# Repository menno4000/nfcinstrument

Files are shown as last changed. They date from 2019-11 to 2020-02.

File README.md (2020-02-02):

# Near Field Groovinator

Fast and easy groove creation

## Arduino racket
We are using an Arduino NANO with the bluetooth HC05 and an NFC Shield as a racket. 
The racket can read notes from RFID chips and send them via bluetooth to the Raspberry Pi. 

You also have two buttons to switch between thh current channel which represents a tone layer (eg. Kick, Snare, HiHat).

## Raspberry Pi 3 - Sequencer, Bluetooth receiver & Displayer
The Raspberry Pi receives signals from the Arduino and starts a Sequencer. 
It will add notes to different channels and start playing them sequentially.

With some hardware knobs and buttons you can control the sequencer and record your notes.

### Displayer
For visual support we will use an already existing LED matrix (16 x MAX7219). 
It will show the programmed sequence and give additional information.

### Hardware-Setup

General Overview of Pins on the Raspberry Pi 3:

Pin Layout


For buttons and the rotary encoder use this table to connect:

| Rotary Encoder | Pins | GPIO |
|---|---|---|
| beat_changer | 11, 13, 15 | 17, 27, 22 |
| bpm_changer | 12, 16, 18 | 18, 23, 24 |
| volume_changer | 29, 31, 32 | 5, 6, 13 |
| Buttons | | |
| play_button | 36 | 16 |
| reset_button | 38 | 20 |
| metro_button | 40 | 21 |
| record_button  | 26 |  7 |

For the Displayer connect your pins from the MAX7219 Matrix to the raspberry according to the following image:

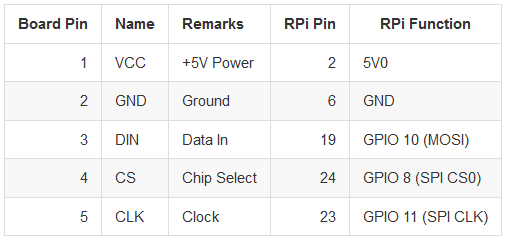
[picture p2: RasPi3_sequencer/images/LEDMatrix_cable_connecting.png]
Cable connection


### Install packages on RasPi:
```
sudo apt-get update

# get Bluetooth setup
sudo apt-get install bluetooth bluez pi-bluetooth blueman

# install python3 and pip3
# follow this tutorial: http://www.knight-of-pi.org/installing-python3-6-on-a-raspberry-pi/

# open spi device port
sudo nano /boot/config.txt
# enable code line: 'dtparam=spi=on'
# reboot
```

To establish a connection between the RasPi and Arduino (via Bluetooth module HC05) execute the following commands on RasPi:
```
# find out macAdress of hc05 or additionally execute 'scan on' in bluetoothctl to find devices
# pair with hc05
sudo bluetoothctl
    agent on
    default-agent
    pair $macAdress
    trust $macAdress
    exit
```

First edit the script ```./start_sequencer.sh``` and change the MAC address to your HC05 value.
Then start it to open the serial port, listen for bluetooth signals and start the sequencer:

```
./start_sequencer.sh
```

If you cant hear anything make sure you are using the right audiosource. With this command you can set your audio output in the Raspberry Pi:

```
# Value: 0 - auto, 1 - analoque (headphone jack), 2 - HDMI
sudo amixer cset numid=3 <value>
```

At some point for whatever reason we could not get the audio anymore from the headphone jack. With an external USB soundcard it was still working. For that you can use these commands:
```
# find the name of your card:
lsusb
# create a configuration file and put the these values with your card number:
sudo nano /etc/asound.conf
	pcm.!default {
	    type hw
	    card 1
	}
	 
	ctl.!default {
	    type hw           
	    card 1
	}
# after that reboot and try sound again:
sudo reboot
# you can also use the builtin mixer:
alsamixer
```

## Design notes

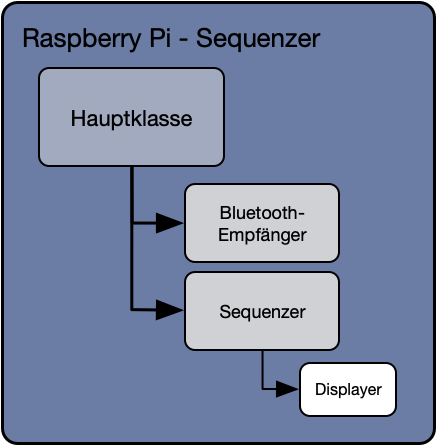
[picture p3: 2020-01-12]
RasPi3_sequencer/images/code-structure.png

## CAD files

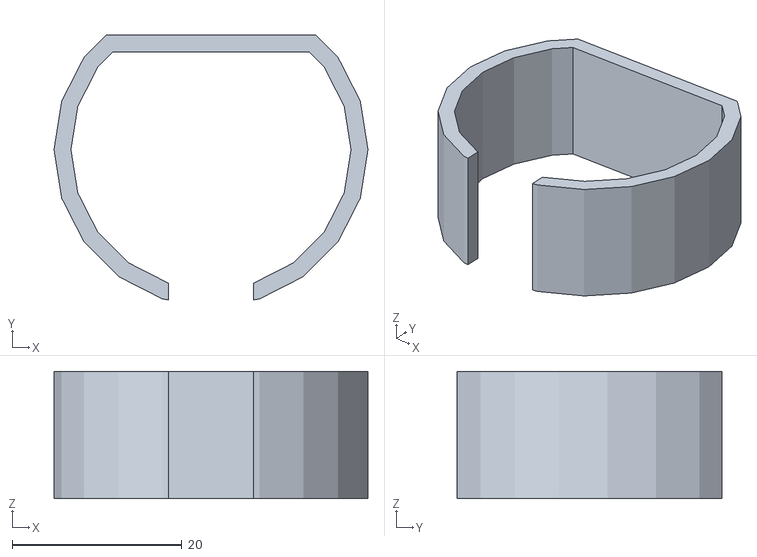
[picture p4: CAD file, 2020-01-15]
3Dmodels/NFC_Button_Holder.stl
37.0 x 31.2 x 15.0

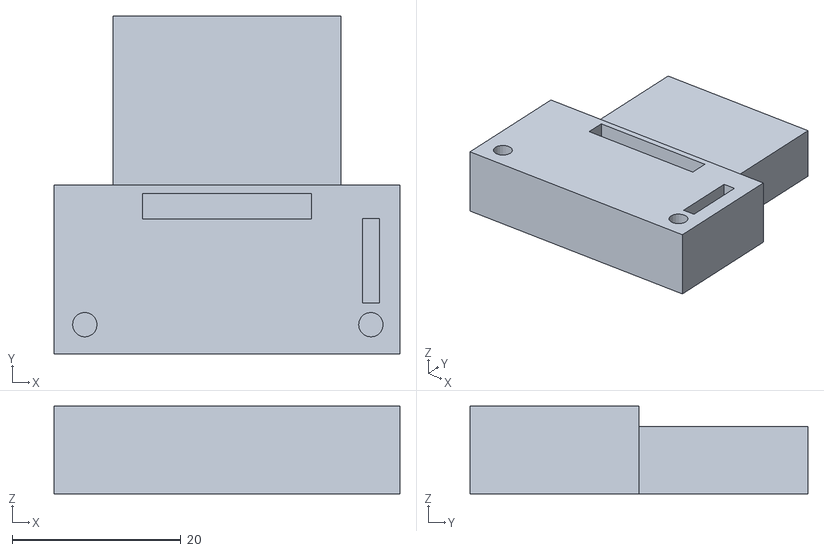
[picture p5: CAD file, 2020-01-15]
3Dmodels/NFC_endpiece.stl
41.0 x 40.0 x 10.4

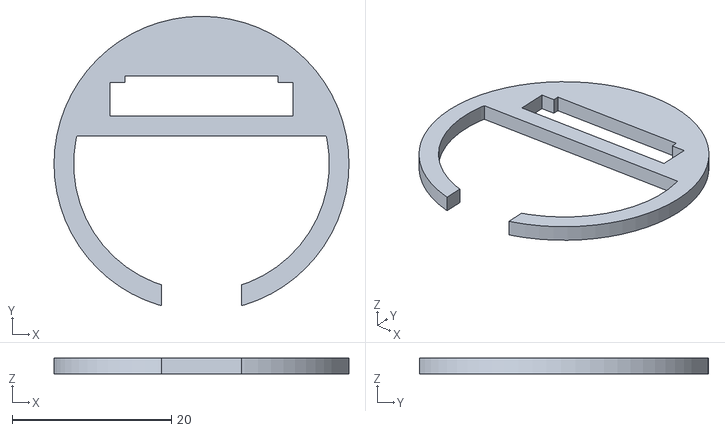
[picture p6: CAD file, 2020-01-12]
3Dmodels/NFC_lineal_guider.stl
37.0 x 36.3 x 2.00

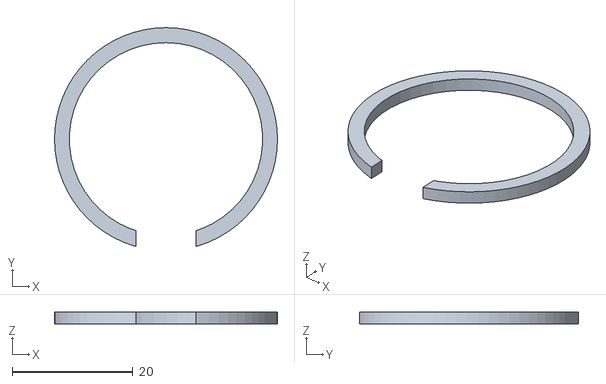
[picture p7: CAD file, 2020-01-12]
3Dmodels/NFC_Powerbank_Ring_open.stl
37.0 x 36.3 x 2.00

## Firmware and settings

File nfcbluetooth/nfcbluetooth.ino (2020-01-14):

#include <SPI.h> // SPI-Bibiothek hinzufügen

#include <MFRC522.h> // RFID-Bibiothek hinzufügen

#define SS_PIN 10 // SDA an Pin 10 

#define RST_PIN 9 // RST an Pin 9 

#define BUTTON1_PIN 2 // Button 2 an Pin 3

#define BUTTON2_PIN 3 // Button 2 an Pin 3

#include <SoftwareSerial.h>

SoftwareSerial hc_05(7, 8); // Bluetooth modul an Pins 7 und 8

MFRC522 mfrc522(SS_PIN, RST_PIN); // RFID-Empfänger benennen
MFRC522::MIFARE_Key key; // MIFARE_Key struct deklarieren


//int period = 100; //Verzoegerung zwischen Bluetooth-Signalen

unsigned long time_now = 0;

//state variablen fuer buttons
int button1State = 0;
int button2State = 0;

void setup() // Beginn des Setups:
{

  Serial.begin(9600); // Serielle Verbindung starten (Monitor)

  SPI.begin(); // SPI-Verbindung aufbauen

  mfrc522.PCD_Init(); // Initialisierung des RFID-Empfängers

  hc_05.begin(9600);

  for (byte i = 0; i < 6; i++) key.keyByte[i] = 0xFF; // MIFARE_Key struct initialisieren

}

//write
int blocknr=1;  //wir wollen den ersten block beschreiben
byte blockcontent[16] = {"13____________"};//16 bytes enthalten den content, der auf die karte geschrieben werden soll

//read
byte readbackblock[18]; // Buffer fuer auslesen von NFC tags

void loop() // Hier beginnt der Loop-Teil
{
  //read buttons

  button1State = digitalRead(BUTTON1_PIN);

  if (button1State == LOW){
    Serial.println("recorded top button press, switching to next instrument");
    hc_05.print("#++");
      delay(500);

    return;
  }

  button2State = digitalRead(BUTTON2_PIN);

  if (button2State == LOW){
    Serial.println("recorded bottom button press, switching to previous instrument");
    hc_05.print("#--");
      delay(500);
 
    return;
  }


  if ( ! mfrc522.PICC_IsNewCardPresent()) // Wenn keine Karte in Reichweite ist...
    return; // ...springt das Programm zurück vor die if-Schleife, womit sich die Abfrage wiederholt.



  if ( ! mfrc522.PICC_ReadCardSerial()) {// Wenn kein RFID-Sender ausgewählt wurde
    return; // ...springt das Programm zurück vor die if-Schleife, womit sich die Abfrage wiederholt.
  }
  Serial.println("card detected.");

//  //dieser abschnitt schreibt die in blockcontent gegebene note auf den ersten block der RFID-karte
//  Serial.println("write block 1");
//  writeBlock(blocknr, blockcontent);

  Serial.println("read block: ");
  readBlock(1, readbackblock); //ersten record der rfid karte einlesen

  String note = "";
  for (int j = 0 ; j < 2 ; j++) //print the block contents
  {
    note = note + (char)readbackblock[j];
  }
  Serial.print("note: ");
  Serial.print(note);

  String noteStubMessage = "%"+note;

  hc_05.print(noteStubMessage);

  delay(500); // Verzoegerung um Mehrfacheingaben einzuschraenken

  Serial.println(""); // Mit dieser Zeile wird auf dem Serial Monitor nur ein Zeilenumbruch gemacht.

  mfrc522.PCD_StopCrypto1(); //RFID tag fuer neue kommunikation resetten
}

//helper methods from https://makecourse.weebly.com/uploads/2/4/7/9/24790373/rfid_tutorial_sketch.zip
int readBlock(int blockNumber, byte arrayAddress[]) 
{
  int largestModulo4Number=blockNumber/4*4;
  int trailerBlock=largestModulo4Number+3;//determine trailer block for the sector

  /*****************************************authentication of the desired block for access***********************************************************/
  byte status = mfrc522.PCD_Authenticate(MFRC522::PICC_CMD_MF_AUTH_KEY_B, trailerBlock, &key, &(mfrc522.uid));
  //byte PCD_Authenticate(byte command, byte blockAddr, MIFARE_Key *key, Uid *uid);
  //this method is used to authenticate a certain block for writing or reading
  //command: See enumerations above -> PICC_CMD_MF_AUTH_KEY_A  = 0x60 (=1100000),    // this command performs authentication with Key A
  //blockAddr is the number of the block from 0 to 15.
  //MIFARE_Key *key is a pointer to the MIFARE_Key struct defined above, this struct needs to be defined for each block. New cards have all A/B= FF FF FF FF FF FF
  //Uid *uid is a pointer to the UID struct that contains the user ID of the card.
  if (status != MFRC522::STATUS_OK) {
         Serial.print("PCD_Authenticate() failed (read): ");
         return 3;//return "3" as error message
  }
  //it appears the authentication needs to be made before every block read/write within a specific sector.
  //If a different sector is being authenticated access to the previous one is lost.


  /*****************************************reading a block***********************************************************/
        
  byte buffersize = 18;//we need to define a variable with the read buffer size, since the MIFARE_Read method below needs a pointer to the variable that contains the size... 
  status = mfrc522.MIFARE_Read(blockNumber, arrayAddress, &buffersize);//&buffersize is a pointer to the buffersize variable; MIFARE_Read requires a pointer instead of just a number
  if (status != MFRC522::STATUS_OK) {
          Serial.print("MIFARE_read() failed: ");
          return 4;//return "4" as error message
  }
  Serial.println("block was read");
  return 0;
}

       
int writeBlock(int blockNumber, byte arrayAddress[]) 
{
  //this makes sure that we only write into data blocks. Every 4th block is a trailer block for the access/security info.
  int largestModulo4Number=blockNumber/4*4;
  int trailerBlock=largestModulo4Number+3;//determine trailer block for the sector
  if (blockNumber > 2 && (blockNumber+1)%4 == 0){Serial.print(blockNumber);Serial.println(" is a trailer block:");return 2;}//block number is a trailer block (modulo 4); quit and send error code 2
  Serial.print(blockNumber);
  Serial.println(" is a data block:");
  
  /*****************************************authentication of the desired block for access***********************************************************/
  byte status = mfrc522.PCD_Authenticate(MFRC522::PICC_CMD_MF_AUTH_KEY_B, trailerBlock, &key, &(mfrc522.uid));
  //byte PCD_Authenticate(byte command, byte blockAddr, MIFARE_Key *key, Uid *uid);
  //this method is used to authenticate a certain block for writing or reading
  //command: See enumerations above -> PICC_CMD_MF_AUTH_KEY_A  = 0x60 (=1100000),    // this command performs authentication with Key A
  //blockAddr is the number of the block from 0 to 15.
  //MIFARE_Key *key is a pointer to the MIFARE_Key struct defined above, this struct needs to be defined for each block. New cards have all A/B= FF FF FF FF FF FF
  //Uid *uid is a pointer to the UID struct that contains the user ID of the card.
  if (status != MFRC522::STATUS_OK) {
         Serial.print("PCD_Authenticate() failed: ");
         return 3;//return "3" as error message
  }
  //it appears the authentication needs to be made before every block read/write within a specific sector.
  //If a different sector is being authenticated access to the previous one is lost.


  /*****************************************writing the block***********************************************************/
        
  status = mfrc522.MIFARE_Write(blockNumber, arrayAddress, 16);//valueBlockA is the block number, MIFARE_Write(block number (0-15), byte array containing 16 values, number of bytes in block (=16))
  //status = mfrc522.MIFARE_Write(9, value1Block, 16);
  if (status != MFRC522::STATUS_OK) {
           Serial.print("MIFARE_Write() failed: ");
           return 4;//return "4" as error message
  }
  Serial.println("block was written");
  return 0;
}

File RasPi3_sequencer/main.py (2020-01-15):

import sys
import time
import os
from os import path
from queue import Queue

import RPi.GPIO as GPIO
from RasPi3_sequencer.util.KY040 import KY040

from RasPi3_sequencer import receiver
from RasPi3_sequencer import sequencer

GPIO.setmode(GPIO.BCM)
play_gpio = 16
reset_gpio = 20
record_gpio = 7
metro_gpio = 21
GPIO.setup(play_gpio, GPIO.IN, pull_up_down=GPIO.PUD_UP)
GPIO.setup(reset_gpio, GPIO.IN, pull_up_down=GPIO.PUD_UP)
GPIO.setup(record_gpio, GPIO.IN, pull_up_down=GPIO.PUD_UP)
GPIO.setup(metro_gpio, GPIO.IN, pull_up_down=GPIO.PUD_UP)

ROOT_DIR = "./RasPi3_sequencer/samples/"
METRO_SAMPLES = [ROOT_DIR + "MetroBeat2.wav", ROOT_DIR + "MetroBar2.wav"]


def beat_change(direction):
    if direction == 1:
        sequencer.interpret_command("beat_up")
    else:
        sequencer.interpret_command("beat_down")


def beat_reset(direction):
    sequencer.interpret_command("beat_reset")


def bpm_change(direction):
    if direction == 1:
        sequencer.interpret_command("bpm_up")
    else:
        sequencer.interpret_command("bpm_down")


def bpm_reset(direction):
    sequencer.interpret_command("bpm_reset")


def volume_change(direction):
    if direction == 1:
        sequencer.interpret_command("volume_up")
    else:
        sequencer.interpret_command("volume_down")


def volume_reset(direction):
    sequencer.interpret_command("volume_reset")


if __name__ == "__main__":
    print("------------------------------------------------------------------------------------------------------------------------")
    print("------------------------------------------------------------------------------------------------------------------------")
    print("------------------------------------------------------------------------------------------------------------------------")
    print("INFO - Starting Script to receive sounds from Arduino via Bluetooth and run Sequencer to make music.")

    # hardware setup for buttons and rotary knobs
    beat_knob = KY040(17, 27, 22, beat_change, beat_reset)
    bpm_knob = KY040(18, 23, 24, bpm_change, bpm_reset)
    volume_knob = KY040(5, 6, 13, volume_change, volume_reset)
    beat_knob.start()
    bpm_knob.start()
    volume_knob.start()

    # reassign root dir if given by command line argument
    if len(sys.argv) > 1:
        ROOT_DIR = sys.argv[1]

    # check if ROOT_DIR exists
    if not path.exists(ROOT_DIR):
        print("ERROR - Given root directory '%s' for samples does not exist. Exiting." % ROOT_DIR)
        sys.exit()

    # setup sound files
    sample_files = []
    for subdir, dirs, files in os.walk(ROOT_DIR):
        for directory in sorted(dirs):
            current_samples = []
            for file in os.listdir(ROOT_DIR + directory):
                if file.endswith(".wav"):
                    current_samples.append(ROOT_DIR + directory + "/" + file)
            sample_files.append(current_samples)

    # queue is used to send signals from one thread to another
    queue = Queue()

    # initialize thread for receiving signals via bluetooth
    bluetooth_input = receiver.ReceiveInput(queue)

    # initialize sequencer with threads: play & listen for input
    sequencer = sequencer.Sequencer(sample_files, METRO_SAMPLES, queue, seq_length=64, note_length=16, start_sequence=True, metro=False)

    # listen endlessly for hardware input
    while True:
        # control bluetooth input with commandline
        #print("INFO - You can type some keywords to control the sequencer via cmd.")
        #print("'play' - starts/pauses sequencer, 'reset' - to delete saved sequence for current channel")
        #print("'show' - displays current configuration, 'metro' - toggles metronome on/off")
        #print("'beat_reset', 'beat_up' & 'beat_down'")
        #print("'bpm_reset', 'bpm_up', 'bpm_down'")
        #print("'volume_reset', 'volume_up', 'volume_down'")
        #command = input()
        #if '#' in command or '%' in command:
        #    queue.put(str(command, 'utf-8'))
        #else:
        #    sequencer_loop.interpret_command(command)

        play_button = GPIO.input(play_gpio)
        reset_button = GPIO.input(reset_gpio)
        record_button = GPIO.input(record_gpio)
        metro_button = GPIO.input(metro_gpio)
        if not play_button:
            sequencer.interpret_command("play")
            time.sleep(0.2)
        if not reset_button:
            sequencer.interpret_command("reset")
            time.sleep(0.2)
        if not record_button:
            sequencer.interpret_command("record")
            time.sleep(0.2)
        if not metro_button:
            sequencer.interpret_command("metro")
            time.sleep(0.2)

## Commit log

2019-11-22 first draft arduino code
2019-11-24 add listener thread to add incoming signals to sequencer channel at right timing
2020-01-08 add samples, add new sound loading logic and be able to play different samples (13)
2020-01-09 added fritzing sketches and 3d model .stl
    [NFC_Breadboard_Schaltung.fzz, NFC_Powerbank_Ring_open.stl, NFC_lineal_guider.stl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]
2020-01-09 fixed miso/mosi mixup, moved resistors to single plate
    [NFC_schaltung.fzz]
2020-01-11 cable color and stripboard for buttons
    [NFC_schaltung.fzz]
2020-01-14 refactor, add metronome again, catch errors
    [displayer.py, main.py, receiver.py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]
2020-01-14 add endpiece and button foundation
    [NFC_Button_Holder.stl, NFC_endpiece.stl]
2020-01-15 add pin connection for preview button
2020-01-15 change record pin
2020-02-02 correct index for preview play
    [sequencer.py]
